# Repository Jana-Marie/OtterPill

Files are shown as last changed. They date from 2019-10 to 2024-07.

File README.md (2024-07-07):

# OtterPill

OtterPill is a 3$ STM32F072 devboard featuring USB 2.0 full-speed, a DFU Bootloader, a USB-PD Phy and Arduino nano alike pinout and size.

Changelog V1.2: BOM cost reduction by ~40%, PCB can be fully populated by JLCSMT, more efficient buck converter (PCB gets less warm at 20V), GND-hook for probing, Reset-Pin exposed as pad, power pads for 20V/5A

**How do I get an OtterPill?**

Via [tindie](https://www.tindie.com/products/jan_henrik/otterpill/) (if sold out DM via Twitter, I might have a few left ;))

## Building, Flashing and Frameworks

### Via Makefile and DFU (C, C++)

Or you can generate a basic firmware, with HAL init and Makefile, with CubeMX. The binary can then be build with make and flashed with dfu-utils. To enter DFU mode, press and hold the Button while plugging in power.

    $ make
    $ dfu-util -a 0 -s 0x08000000:leave -D build/firmware.bin

### Via Arduino

[You can build and flash the firmware via Arduino as described here.](https://github.com/stm32duino/Arduino_Core_STM32)

### Via PlatformIO

[https://gist.github.com/ansemjo/ab1c12f7c78abb140f7272501aff2a55](https://gist.github.com/ansemjo/ab1c12f7c78abb140f7272501aff2a55) Thank you [ansemjo](https://github.com/ansemjo) :3

### Via Nodate (野点) (C++, Ada)

[https://github.com/MayaPosch/Nodate](https://github.com/MayaPosch/Nodate)

### Rust

Thank you [@jamesmunns](https://github.com/jamesmunns)! :3

[https://github.com/jamesmunns/OtterPill-rs](https://github.com/jamesmunns/OtterPill-rs)

## Schematic

[HW v1.2/OtterPill.pdf](HW%20v1.2/OtterPill.pdf)

## Pinout

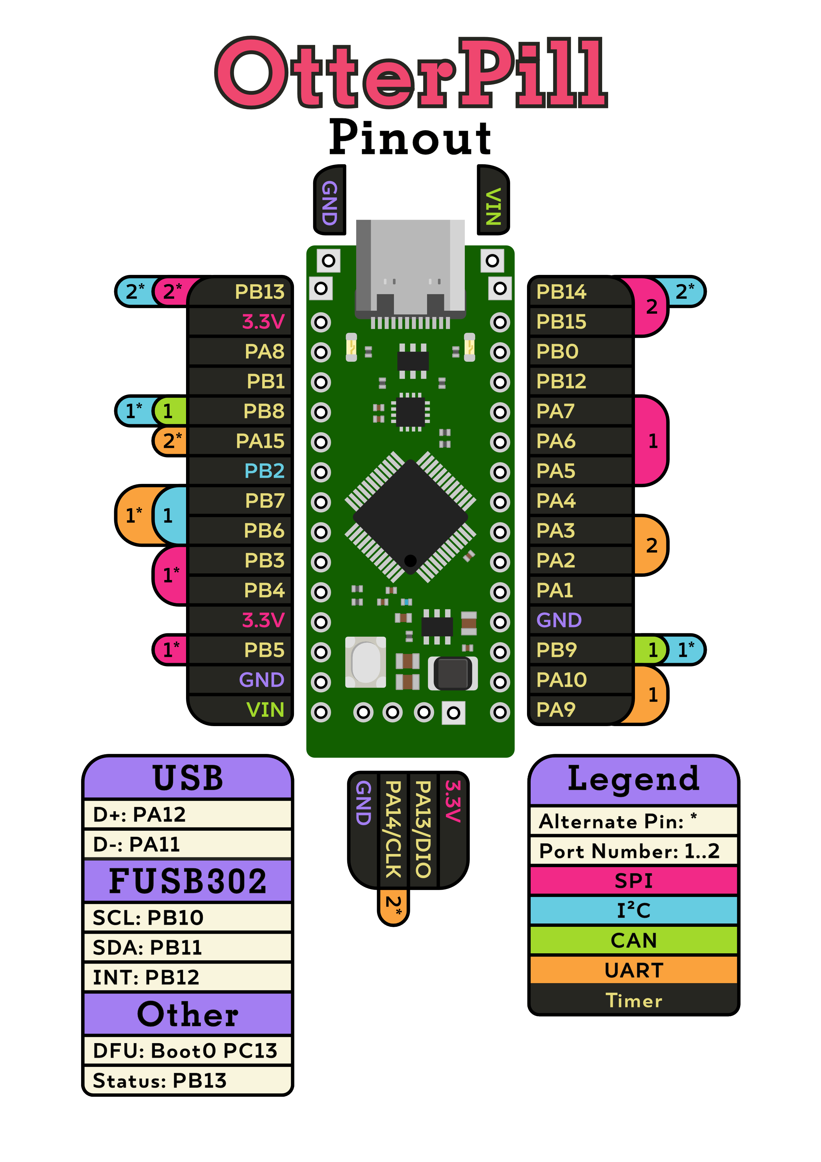
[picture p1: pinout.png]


Pinout by [SarahhhhFoster](https://github.com/SarahhhhFoster) :)

## Examples and projects

### Blink example firmware

[Blink/](Blink/)

### STM workshop based on OtterPill

[https://github.com/Jana-Marie/hackerhotel-stm-workshop](https://github.com/Jana-Marie/hackerhotel-stm-workshop)



### USB-PD example firmware

This is a working USB-PD example using ChibiOS, a new voltage can be requested by pressing the Button.

[https://github.com/Jana-Marie/USB-PD-Firmware](https://github.com/Jana-Marie/USB-PD-Firmware)

### IBM dials retrofit

[https://github.com/Jana-Marie/IBM-dials-retrofit](https://github.com/Jana-Marie/IBM-dials-retrofit)



## Shields and addons

Most Arduino shields should be compatible.

#### [USB-to-CAN-adapter](https://github.com/Jana-Marie/OtterPill-CAN-Adapter)

## Todo for HW v1.3

 - [x] Replace U1 with ESDU5V0H4
 - [x] ~~Add a TVS Diode to VBUS (e.g. SJD12A22L01)~~ -> Added series resistor to reduce ringing
 - [ ] Remove R8, R9
 - [x] ~~Redraw the FUSB302B Symbol~~ -> forgot why, works great
 - [x] ~~Consider switching to STUSB4500 (Easier PD requesting, same price)~~ -> FUSB works great, no need to change
 - [x] Add VBUS ADC

## Special thanks

[@jamesmunns](https://github.com/jamesmunns) for creating the Rust examples.

[@MayaPosch](https://github.com/MayaPosch) for creating the Nodate framework and adding the OtterPill.

[@ansemjo](https://github.com/ansemjo) for creating a PlatformIO configuration.

[@SarahhhhFoster](https://github.com/SarahhhhFoster) for creating the awesome pinout diagram.

## Images

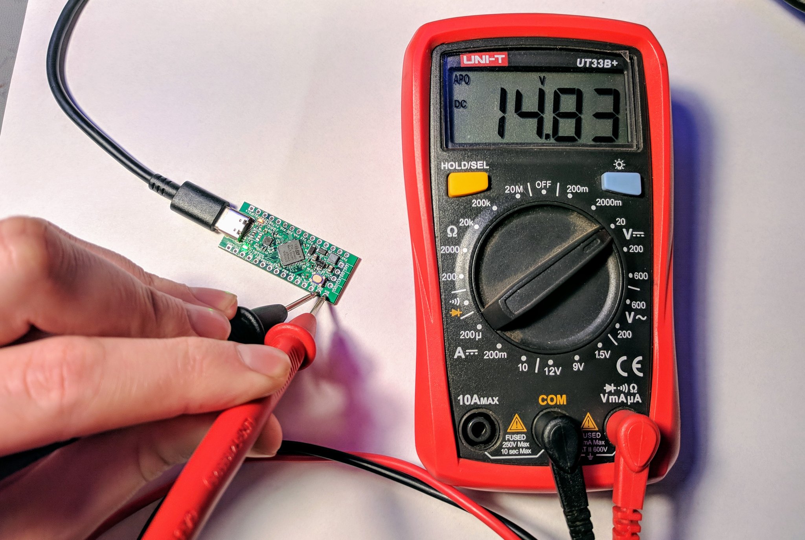
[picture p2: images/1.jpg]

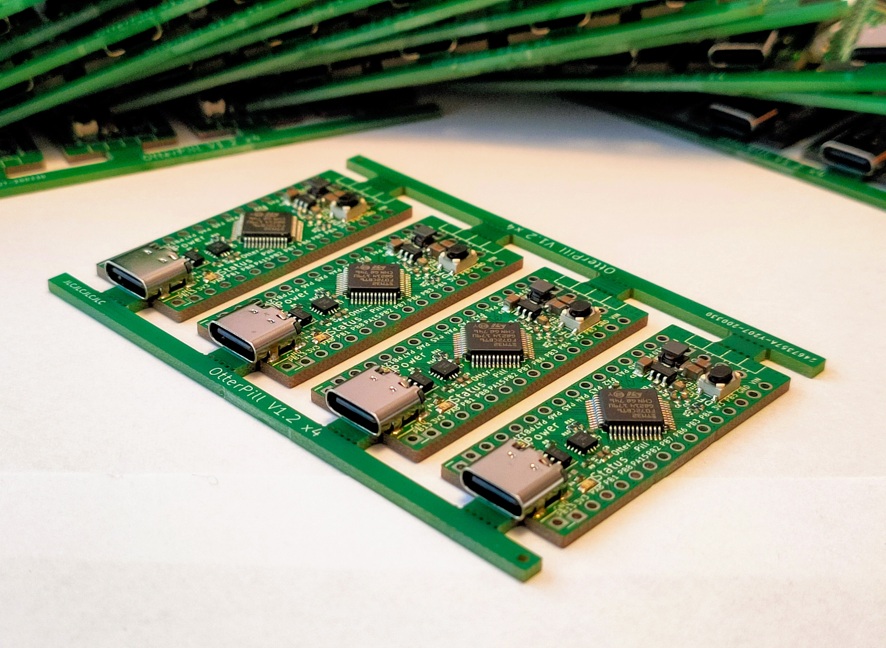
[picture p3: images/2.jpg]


### Rev 1.2

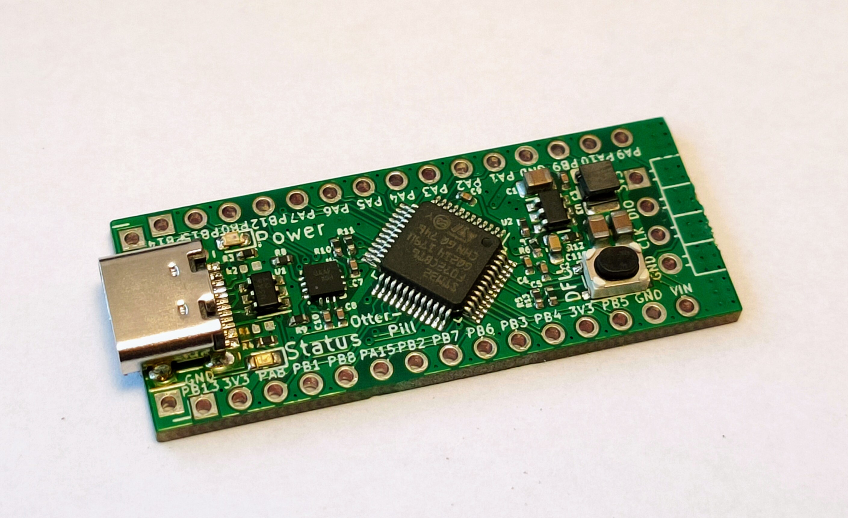
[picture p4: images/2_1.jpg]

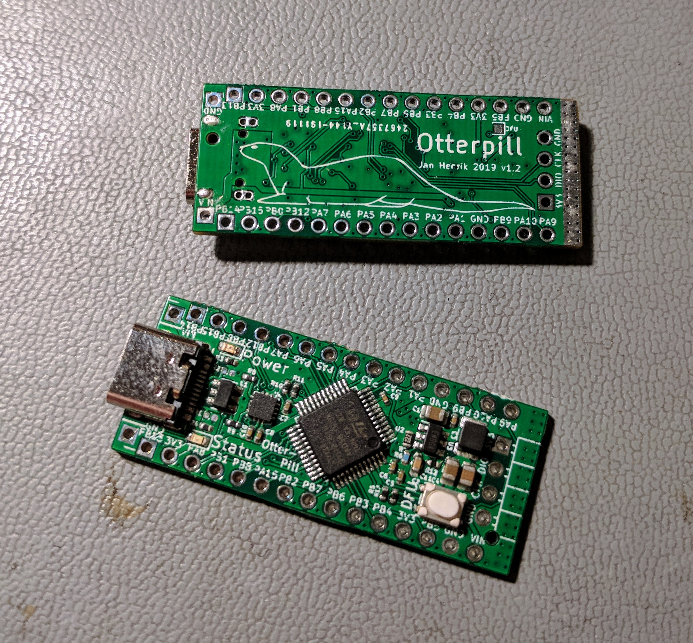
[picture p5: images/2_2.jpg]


### License

Copyright Jana Marie Hemsing 2027.

This source describes Open Hardware and is licensed under the CERN-OHL-S v2.

You may redistribute and modify this source and make products using it under
the terms of the CERN-OHL-S v2 (https://ohwr.org/cern_ohl_s_v2.txt).

This source is distributed WITHOUT ANY EXPRESS OR IMPLIED WARRANTY,
INCLUDING OF MERCHANTABILITY, SATISFACTORY QUALITY AND FITNESS FOR A
PARTICULAR PURPOSE. Please see the CERN-OHL-S v2 for applicable conditions.

Source location: https://github.com/Jana-Marie/OtterPill

As per CERN-OHL-S v2 section 4, should You produce hardware based on this
source, You must where practicable maintain the Source Location visible
on the external case of the Gizmo or other products you make using this
source.

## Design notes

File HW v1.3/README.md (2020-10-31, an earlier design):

# OtterPill

Hardware rev 1.3 not tested, gerber are broken.

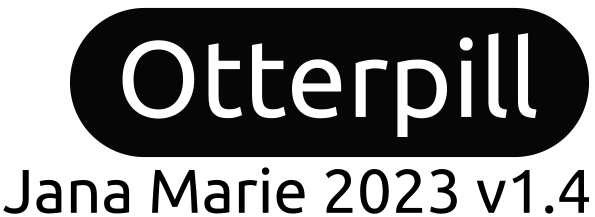
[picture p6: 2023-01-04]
HW v1.4/otterpill_1200.png

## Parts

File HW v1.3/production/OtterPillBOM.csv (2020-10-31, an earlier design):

Comment | Designator | Footprint | LCSC
10u 25V | C1,C4,C11 | Capacitor_SMD:C_0805_2012Metric | C15850
100n 50V | C2 | Capacitor_SMD:C_0603_1608Metric | C14663
100n 50V | C3,C5,C6,C7,C8,C9,C10,C12 | Capacitor_SMD:C_0402_1005Metric | C1525
LED RED | D1 | LED_SMD:LED_0603_1608Metric | C2286
LED GREEN | D2 | LED_SMD:LED_0603_1608Metric | C72043
USB-c | J1 | otter:USB-C 16Pin
4u7 | L1 | Inductor_SMD:L_1210_3225Metric | C86070
DNP | R1,R2 | Resistor_SMD:R_0402_1005Metric | dnp
100 | R13 | Resistor_SMD:R_0402_1005Metric | C25076
1 | R16 | Resistor_SMD:R_0603_1608Metric | C22936
3k3 | R5,R3,R4,R10,R11 | Resistor_SMD:R_0402_1005Metric | C25890
100k | R6,R12,R14 | Resistor_SMD:R_0402_1005Metric | C25741
22k | R7,R15 | Resistor_SMD:R_0402_1005Metric | C25768
0 | R8,R9 | Resistor_SMD:R_0402_1005Metric | C17168
DFU | SW1 | Button_Switch_SMD:SW_SPST_PTS810
USBLC6-4 | U1 | Package_TO_SOT_SMD:SOT-23-6 | C111212
STM32F072C8Tx | U2 | Package_QFP:LQFP-48_7x7mm_P0.5mm | C80488
SY8201 | U3 | Package_TO_SOT_SMD:SOT-23-6 | C108052
FUSB302BMPX | U4 | Package_DFN_QFN:WQFN-14-1EP_2.5x2.5mm_P0.5mm_EP1.45x1.45mm | C132291

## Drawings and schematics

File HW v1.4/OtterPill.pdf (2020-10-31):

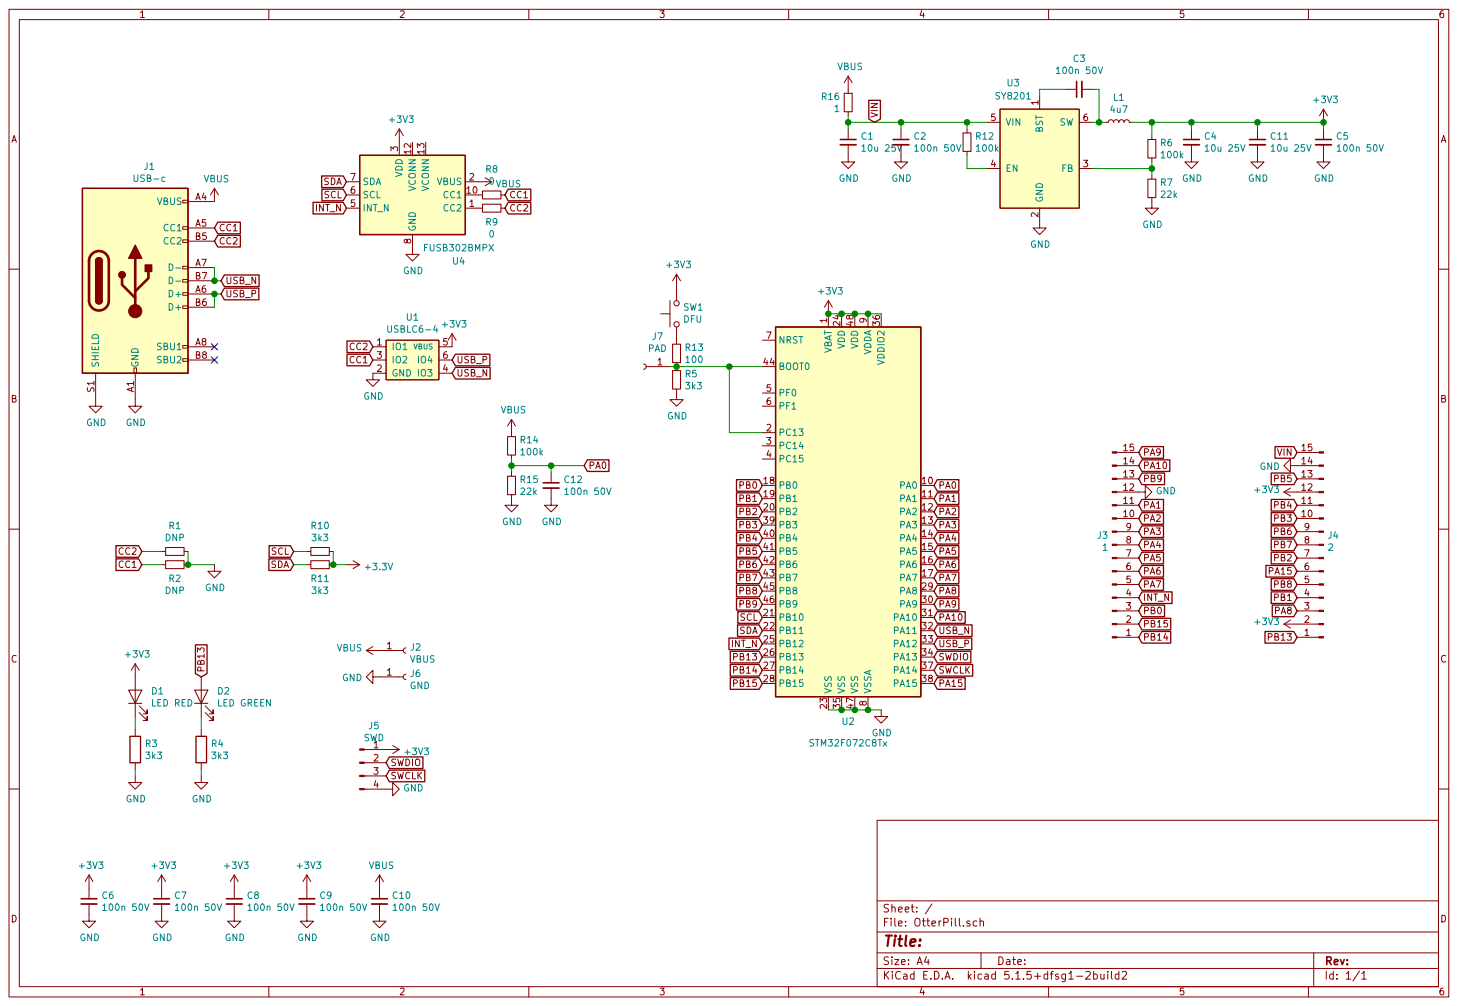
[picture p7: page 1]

2 FB 3 EN 4 VIN 5 SW 6 U3 SY8201 VBUS

1 PA0 10 PA1 11 PA2 12 PA3 13 PA4 14 PA5 15 PA6 16 PA7 17 PB0 18 PB1 19 PC13 2 PB2 20 PB10 21 PB11 22 VSS 23 VDD 24 PB12 25 PB13 26 PB14 27 PB15 28 PA8 29 PC14 3 PA9 30 PA10 31 PA11 32 PA12 33 PA13 34 VSS 35 VDDIO2 36 PA14 37 PA15 38 PB3 39 PC15 4 PB4 40 PB5 41 PB6 42 PB7 43 BOOT0 44 PB8 45 PB9 46 VSS 47 VDD 48 PF0 5 PF1 6 NRST 7 VSSA

Id: 1/1 Title: File: OtterPill.sch Sheet: / C12

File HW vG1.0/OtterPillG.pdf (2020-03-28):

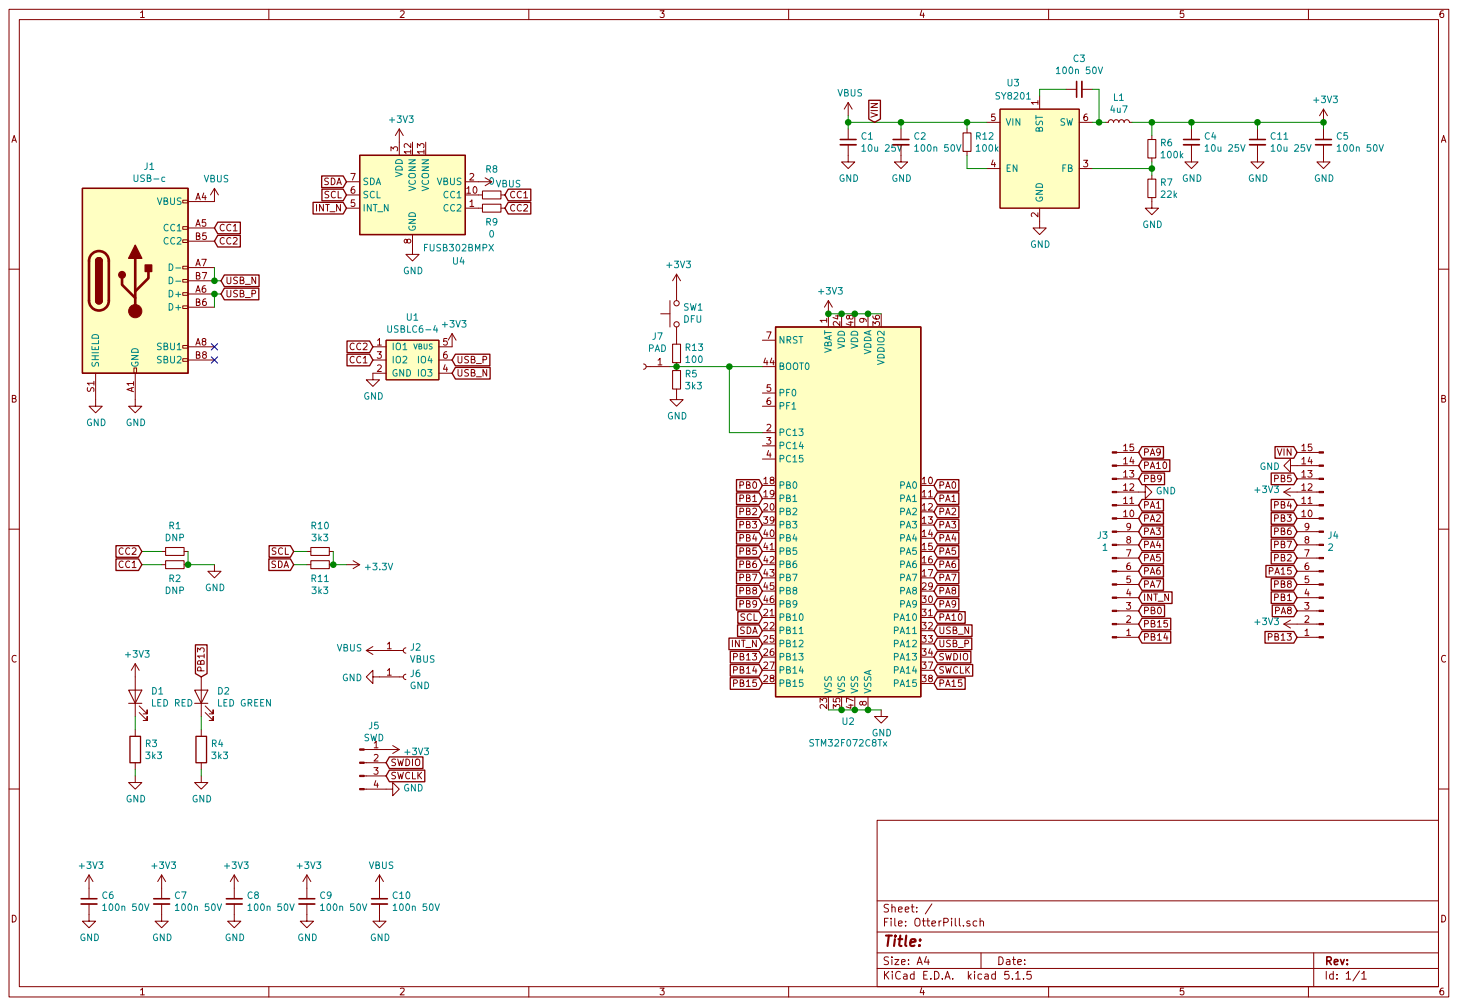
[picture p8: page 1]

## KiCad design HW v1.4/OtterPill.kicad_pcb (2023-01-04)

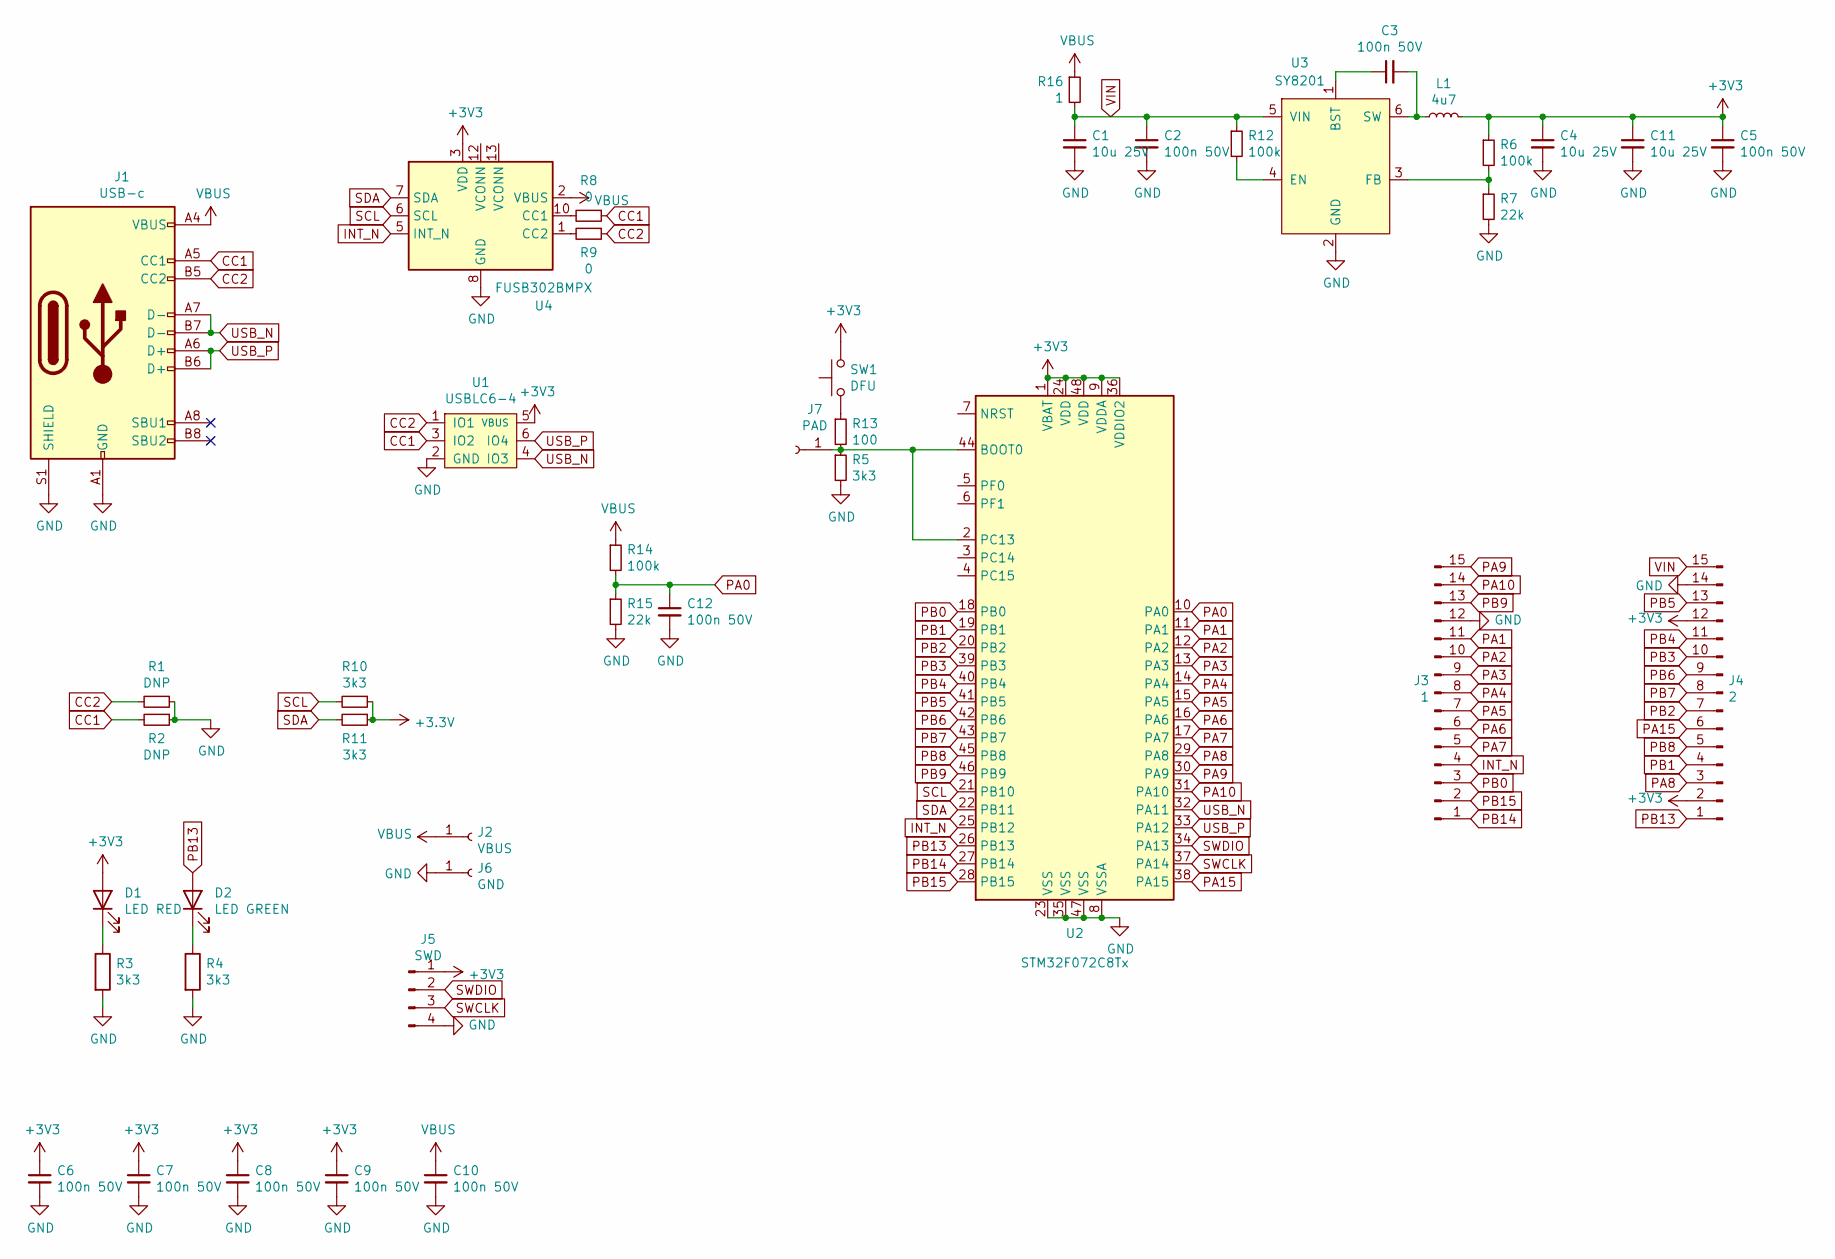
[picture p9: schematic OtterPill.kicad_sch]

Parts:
C1, C4, C11: 10u 25V; C_0805_2012Metric; LCSC C15850
C2: 100n 50V; C_0603_1608Metric
C3, C5, C6, C7, C8, C9, C10, C12: 100n 50V; C_0402_1005Metric
D1: LED RED; LED_0603_1608Metric
D2: LED GREEN; LED_0603_1608Metric
J1: USB-c; USB-C 16Pin
J2: VBUS; PinHeader_1x01_P2.54mm_Vertical
J3: 1; PinHeader_1x15_P2.54mm_Vertical
J4: 2; PinHeader_1x15_P2.54mm_Vertical
J5: SWD; PinHeader_1x04_P2.54mm_Horizontal
J6: GND; PinHeader_1x01_P2.54mm_Vertical
J7: PAD; TestPoint_Pad_1.0x1.0mm
L1: 4u7; L_1210_3225Metric; LCSC C86070
R1, R2: DNP; R_0402_1005Metric
R3, R4, R5, R10, R11: 3k3; R_0402_1005Metric
R6, R12, R14: 100k; R_0402_1005Metric
R7, R15: 22k; R_0402_1005Metric
R8, R9: 0; R_0402_1005Metric
R13: 100; R_0402_1005Metric
R16: 1; R_0603_1608Metric
SW1: DFU; SW_SPST_PTS810
U1: USBLC6-4; SOT-23-6
U2: STM32F072C8Tx; LQFP-48_7x7mm_P0.5mm
U3: SY8201; SOT-23-6
U4: FUSB302BMPX; WQFN-14-1EP_2.5x2.5mm_P0.5mm_EP1.45x1.45mm

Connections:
CC1: J1.A5 (CC1), R2.2, R8.1, U1.3 (IO2)
CC2: J1.B5 (CC2), R1.2, R9.1, U1.1 (IO1)
GND: C1.2, C2.2, C4.2, C5.2, C6.2, C7.2, C8.2, C9.2, C10.2, C11.2, C12.2, J1.A1 (GND), J1.A12 (GND), J1.B1 (GND), J1.B12 (GND), J1.S1 (SHIELD), J3.12, J4.14, J5.4, J6.1, R1.1, R2.1, R3.2, R4.2, R5.2, R7.2, R15.2, U1.2 (GND), U2.8 (VSSA), U2.23 (VSS), U2.35 (VSS), U2.47 (VSS), U3.2 (GND), U4.8 (GND), U4.9 (GND), U4.15 (GND)
INT_N: J3.4, U2.25 (PB12), U4.5 (INT_N)
unnamed: C3.1, U3.1 (BST)
unnamed: C3.2, L1.1, U3.6 (SW)
unnamed: D1.1 (K), R3.1
unnamed: D2.1 (K), R4.1
unnamed: J7.1, R5.1, R13.2, U2.2 (PC13), U2.44 (BOOT0)
unnamed: R6.2, R7.1, U3.3 (FB)
unnamed: R8.2, U4.10 (CC1), U4.11 (CC1)
unnamed: R9.2, U4.1 (CC2), U4.14 (CC2)
unnamed: R12.2, U3.4 (EN)
unnamed: R13.1, SW1.1
PA0: C12.1, R14.2, R15.1, U2.10 (PA0)
PA1: J3.11, U2.11 (PA1)
PA2: J3.10, U2.12 (PA2)
PA3: J3.9, U2.13 (PA3)
PA4: J3.8, U2.14 (PA4)
PA5: J3.7, U2.15 (PA5)
PA6: J3.6, U2.16 (PA6)
PA7: J3.5, U2.17 (PA7)
PA8: J4.3, U2.29 (PA8)
PA9: J3.15, U2.30 (PA9)
PA10: J3.14, U2.31 (PA10)
PA15: J4.6, U2.38 (PA15)
PB0: J3.3, U2.18 (PB0)
PB1: J4.4, U2.19 (PB1)
PB2: J4.7, U2.20 (PB2)
PB3: J4.10, U2.39 (PB3)
PB4: J4.11, U2.40 (PB4)
PB5: J4.13, U2.41 (PB5)
PB6: J4.9, U2.42 (PB6)
PB7: J4.8, U2.43 (PB7)
PB8: J4.5, U2.45 (PB8)
PB9: J3.13, U2.46 (PB9)
PB13: D2.2 (A), J4.1, U2.26 (PB13)
PB14: J3.1, U2.27 (PB14)
PB15: J3.2, U2.28 (PB15)
SCL: R10.2, U2.21 (PB10), U4.6 (SCL)
SDA: R11.2, U2.22 (PB11), U4.7 (SDA)
SWCLK: J5.3, U2.37 (PA14)
SWDIO: J5.2, U2.34 (PA13)
USB_N: J1.A7 (D-), J1.B7 (D-), U1.4 (IO3), U2.32 (PA11)
USB_P: J1.A6 (D+), J1.B6 (D+), U1.6 (IO4), U2.33 (PA12)
VBUS: C10.1, J1.A4 (VBUS), J1.A9 (VBUS), J1.B4 (VBUS), J1.B9 (VBUS), J2.1, R14.1, R16.1, U4.2 (VBUS)
VIN: C1.1, C2.1, J4.15, R12.1, R16.2, U3.5 (VIN)

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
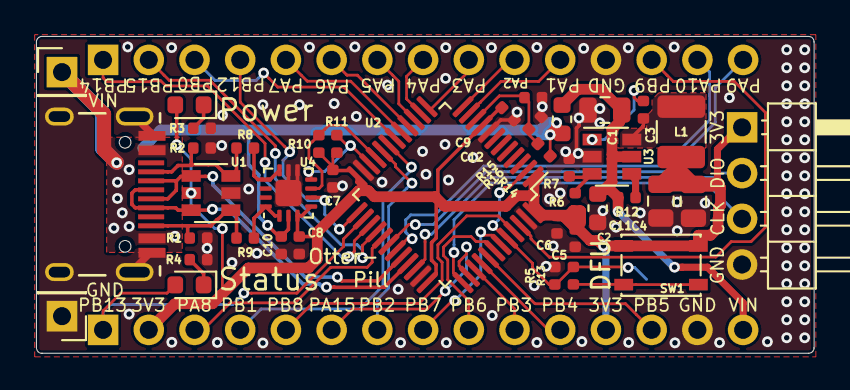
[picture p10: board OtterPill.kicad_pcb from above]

Board: 2 copper layers, 43.2 x 17.6 mm, 43 parts (1 on the bottom side), 48 nets.

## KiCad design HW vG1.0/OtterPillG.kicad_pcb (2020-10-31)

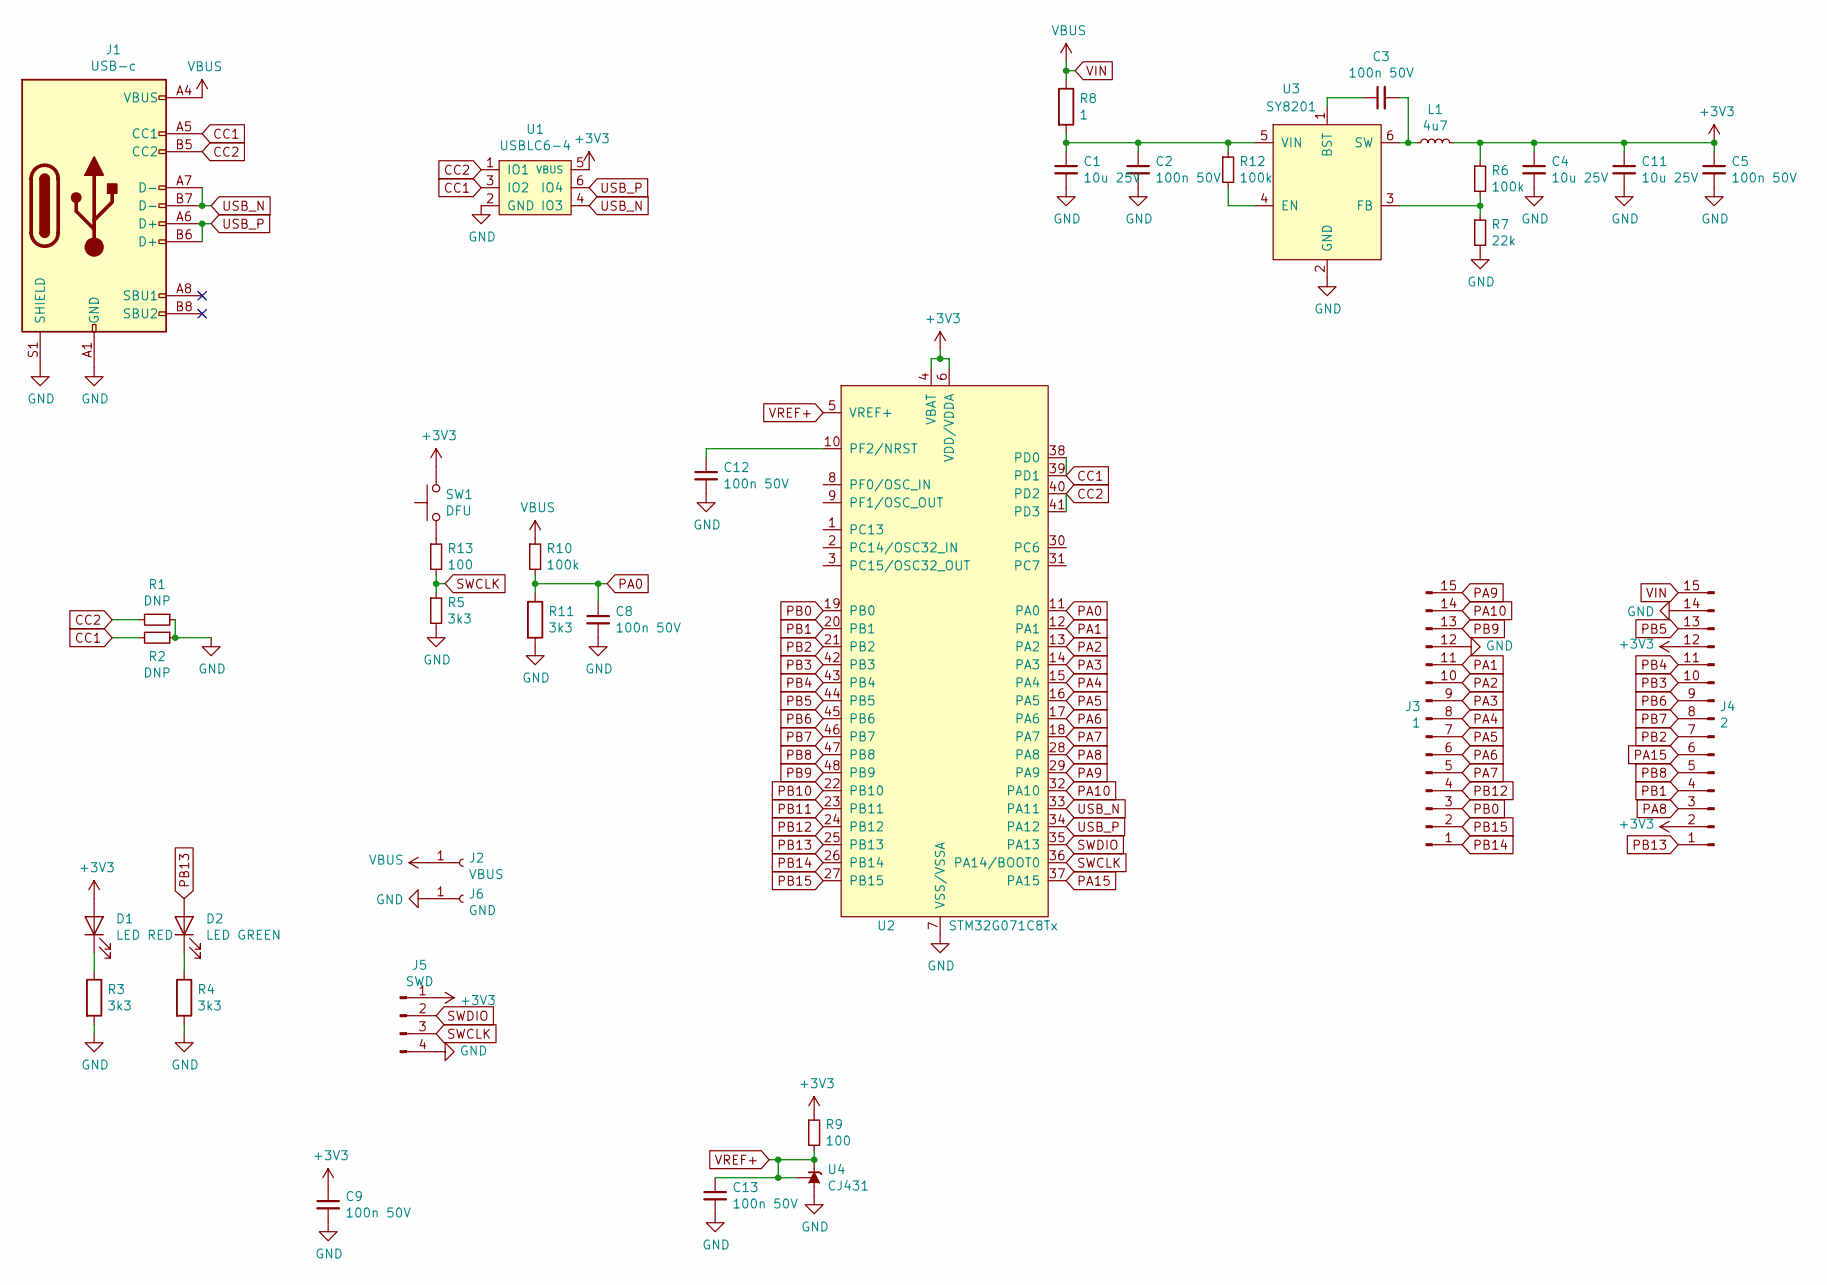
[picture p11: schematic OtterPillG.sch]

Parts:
C1, C4, C11: 10u 25V; C_0805; LCSC C15850
C2: 100n 50V; C_0603
C3, C5, C8, C9, C12, C13: 100n 50V; C_0402
D1: LED RED; LED_0603_1608Metric
D2: LED GREEN; LED_0603_1608Metric
J1: USB-c; USB-C 16Pin
J2: VBUS; PinHeader_1x01_P2.54mm_Vertical
J3: 1; PinHeader_1x15_P2.54mm_Vertical
J4: 2; PinHeader_1x15_P2.54mm_Vertical
J5: SWD; PinHeader_1x04_P2.54mm_Horizontal
J6: GND; PinHeader_1x01_P2.54mm_Vertical
L1: 4u7; L_1210_3225Metric; LCSC C86070
R1, R2: DNP; R_0402
R3, R4, R5, R11: 3k3; R_0402
R6, R10, R12: 100k; R_0402
R7: 22k; R_0402
R8: 1; R_0805
R9, R13: 100; R_0402
SW1: DFU; SW_SPST_PTS810
U1: USBLC6-4; SOT-23-6
U2: STM32G071C8Tx; TQFP-48_7x7mm_P0.5mm
U3: SY8201; SOT-23-6
U4: CJ431; SOT-23

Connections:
+3V3: C4.1, C5.1, C9.1, C11.1, D1.2 (A), J4.2, J4.12, J5.1, L1.2, R6.1, R9.1, SW1.2, U1.5 (VBUS), U2.4 (VBAT), U2.6 (VDD/VDDA)
CC1: J1.A5 (CC1), R2.2, U1.3 (IO2), U2.38 (PD0), U2.39 (PD1)
CC2: J1.B5 (CC2), R1.2, U1.1 (IO1), U2.40 (PD2), U2.41 (PD3)
GND: C1.2, C2.2, C4.2, C5.2, C8.2, C9.2, C11.2, C12.2, C13.2, J1.A1 (GND), J1.A12 (GND), J1.B1 (GND), J1.B12 (GND), J1.S1 (SHIELD), J3.12, J4.14, J5.4, J6.1, R1.1, R2.1, R3.2, R4.2, R5.2, R7.2, R11.2, U1.2 (GND), U2.7 (VSS/VSSA), U3.2 (GND), U4.3 (A)
unnamed: C1.1, C2.1, R8.2, R12.1, U3.5 (VIN)
unnamed: C3.1, U3.1 (BST)
unnamed: C3.2, L1.1, U3.6 (SW)
unnamed: C12.1, U2.10 (PF2/NRST)
unnamed: D1.1 (K), R3.1
unnamed: D2.1 (K), R4.1
unnamed: R6.2, R7.1, U3.3 (FB)
unnamed: R12.2, U3.4 (EN)
unnamed: R13.1, SW1.1
PA0: C8.1, R10.2, R11.1, U2.11 (PA0)
PA1: J3.11, U2.12 (PA1)
PA2: J3.10, U2.13 (PA2)
PA3: J3.9, U2.14 (PA3)
PA4: J3.8, U2.15 (PA4)
PA5: J3.7, U2.16 (PA5)
PA6: J3.6, U2.17 (PA6)
PA7: J3.5, U2.18 (PA7)
PA8: J4.3, U2.28 (PA8)
PA9: J3.15, U2.29 (PA9)
PA10: J3.14, U2.32 (PA10)
PA15: J4.6, U2.37 (PA15)
PB0: J3.3, U2.19 (PB0)
PB1: J4.4, U2.20 (PB1)
PB2: J4.7, U2.21 (PB2)
PB3: J4.10, U2.42 (PB3)
PB4: J4.11, U2.43 (PB4)
PB5: J4.13, U2.44 (PB5)
PB6: J4.9, U2.45 (PB6)
PB7: J4.8, U2.46 (PB7)
PB8: J4.5, U2.47 (PB8)
PB9: J3.13, U2.48 (PB9)
PB10: U2.22 (PB10)
PB11: U2.23 (PB11)
PB12: J3.4, U2.24 (PB12)
PB13: D2.2 (A), J4.1, U2.25 (PB13)
PB14: J3.1, U2.26 (PB14)
PB15: J3.2, U2.27 (PB15)
SWCLK: J5.3, R5.1, R13.2, U2.36 (PA14/BOOT0)
SWDIO: J5.2, U2.35 (PA13)
USB_N: J1.A7 (D-), J1.B7 (D-), U1.4 (IO3), U2.33 (PA11)
USB_P: J1.A6 (D+), J1.B6 (D+), U1.6 (IO4), U2.34 (PA12)
VIN: J1.A4 (VBUS), J1.A9 (VBUS), J1.B4 (VBUS), J1.B9 (VBUS), J2.1, J4.15, R8.1, R10.1
VREF+: C13.1, R9.2, U2.5 (VREF+), U4.1 (REF), U4.2 (K)

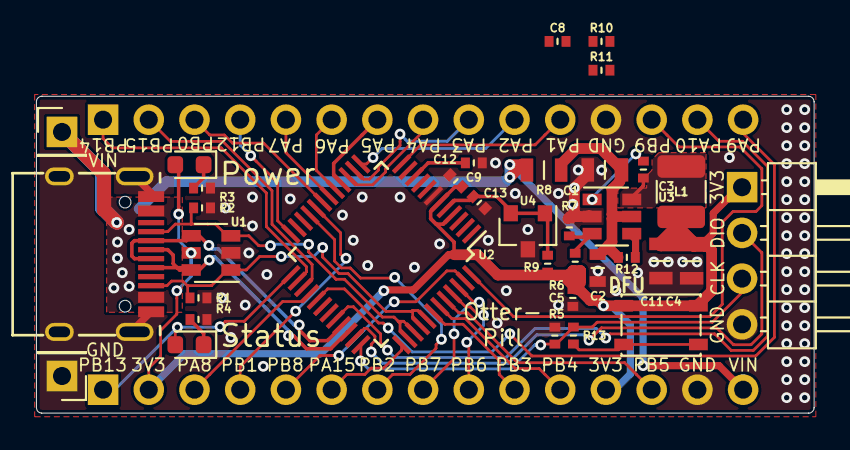
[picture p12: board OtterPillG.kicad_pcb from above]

Board: 2 copper layers, 43.2 x 17.6 mm, 37 parts (0 on the bottom side), 45 nets.

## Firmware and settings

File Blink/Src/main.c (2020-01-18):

#include "main.h"

void SystemClock_Config(void);
static void MX_GPIO_Init(void);

int main(void)
{
  HAL_Init();
  SystemClock_Config();

  MX_GPIO_Init();

  while (1)
  {
    HAL_GPIO_WritePin(GPIOB,GPIO_PIN_13,1);
    HAL_Delay(1000);
    HAL_GPIO_WritePin(GPIOB,GPIO_PIN_13,0);
    HAL_Delay(1000);
  }
}

void SystemClock_Config(void)
{
  RCC_OscInitTypeDef RCC_OscInitStruct = {0};
  RCC_ClkInitTypeDef RCC_ClkInitStruct = {0};

  RCC_OscInitStruct.OscillatorType = RCC_OSCILLATORTYPE_HSI;
  RCC_OscInitStruct.HSIState = RCC_HSI_ON;
  RCC_OscInitStruct.HSICalibrationValue = RCC_HSICALIBRATION_DEFAULT;
  RCC_OscInitStruct.PLL.PLLState = RCC_PLL_NONE;
  HAL_RCC_OscConfig(&RCC_OscInitStruct);

  RCC_ClkInitStruct.ClockType = RCC_CLOCKTYPE_HCLK|RCC_CLOCKTYPE_SYSCLK
                              |RCC_CLOCKTYPE_PCLK1;
  RCC_ClkInitStruct.SYSCLKSource = RCC_SYSCLKSOURCE_HSI;
  RCC_ClkInitStruct.AHBCLKDivider = RCC_SYSCLK_DIV1;
  RCC_ClkInitStruct.APB1CLKDivider = RCC_HCLK_DIV1;

  HAL_RCC_ClockConfig(&RCC_ClkInitStruct, FLASH_LATENCY_0);
}

static void MX_GPIO_Init(void)
{
  GPIO_InitTypeDef GPIO_InitStruct = {0};

  __HAL_RCC_GPIOB_CLK_ENABLE();
  __HAL_RCC_GPIOA_CLK_ENABLE();

  HAL_GPIO_WritePin(GPIOB, GPIO_PIN_13, GPIO_PIN_RESET);

  GPIO_InitStruct.Pin = GPIO_PIN_13;
  GPIO_InitStruct.Mode = GPIO_MODE_OUTPUT_PP;
  GPIO_InitStruct.Pull = GPIO_NOPULL;
  GPIO_InitStruct.Speed = GPIO_SPEED_FREQ_LOW;
  HAL_GPIO_Init(GPIOB, &GPIO_InitStruct);

}

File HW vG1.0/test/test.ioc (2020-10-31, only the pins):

Mcu.UserName=STM32G071C8Tx
PA1.Signal=ADC1_IN1
PA13.Signal=SYS_SWDIO
PA14-BOOT0.Signal=SYS_SWCLK
PA2.Signal=LPUART1_TX
PA3.Signal=LPUART1_RX
PB13.Signal=GPIO_Output
PD0.Signal=UCPD2_CC1
PD1.Signal=UCPD2_DBCC1
PD2.Signal=UCPD2_CC2
PD3.Signal=UCPD2_DBCC2

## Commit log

2019-05-05 initital commit
    [OtterPill.kicad_pcb, OtterPill.sch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]
2019-05-06 added gerber
    [OtterPill-B_Cu.gbl, OtterPill-B_Mask.gbs, OtterPill-B_Paste.gbp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]
2019-10-16 updated PCB and gerber
    [OtterPill-B.Cu.gbl, OtterPill-B.Mask.gbs, OtterPill-B.Paste.gbp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]
2019-10-16 updated gerber
    [OtterPill-B.Cu.gbl, OtterPill-B.Mask.gbs, OtterPill-B.Paste.gbp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]
2019-10-16 removed old gerber
    [OtterPill-B_Cu.gbl, OtterPill-B_Mask.gbs, OtterPill-B_Paste.gbp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]
2019-10-18 added BOM
    [OtterPill.csv]
2019-10-20 updated otterpill to V1.2
    [OtterPill.csv, OtterPill.kicad_pcb, OtterPill.sch]
2019-10-23 added HW 1.1 files
    [OtterPill-B.Cu.gbl, OtterPill-B.Mask.gbs, OtterPill-B.Paste.gbp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]
2019-10-23 moved HW 1.2 files
    [1-click-bom.tsv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]
2019-10-24 updated V1.2
    [OtterPill-B.Cu.gbl, OtterPill-B.Mask.gbs, OtterPill-B.Paste.gbp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]
2019-11-17 finalized V1.2
    [1-click-bom.tsv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]
2019-12-20 updated values
    [OtterPill.sch, OtterPillBOM.csv]
2019-12-21 schematic cleanup
    [OtterPill.kicad_pcb, OtterPill.sch]
2019-12-21 fixed bom
    [OtterPill.csv]
2020-01-25 Add OtterPill v1.2 Schematic PDF
2020-03-28 added x4 production files
    [OtterPill-top-pos.csv]
2020-03-28 added edgerails
    [edgerails-B_Cu.gbl, edgerails-B_Mask.gbs, edgerails-B_Paste.gbp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]
2020-03-28 updated bom
    [OtterPillBOM.csv]
2020-04-15 added boms
    [OtterPill-top-pos-x2.csv, OtterPill-top-pos-x4.csv]
2020-04-15 fixed 100k
    [OtterPillBOM.csv]
2020-04-22 added images
    [OtterPill.kicad_pcb]
2020-09-14 added G072 version
    [OtterPill-B_Cu.gbl, OtterPill-B_Mask.gbs, OtterPill-B_Paste.gbp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]
2020-09-14 removed old files
    [OtterPill-B_Cu.gbl, OtterPill-B_Mask.gbs, OtterPill-B_Paste.gbp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]
2020-10-31 updated v1.3
    [OtterPill-B_Cu.gbl, OtterPill-B_Mask.gbs, OtterPill-B_Paste.gbp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]
2020-10-31 updated vG1.0
    [OtterPillG-B_Cu.gbl, OtterPillG-B_Mask.gbs, OtterPillG-B_Paste.gbp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]
2020-10-31 added production files
    [OtterPillBOM.csv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]
2023-01-04 added kicad files
    [OtterPill.kicad_pcb, OtterPill.kicad_sch]
2023-01-04 added silkscreen art
2023-01-04 fixed schematic issue
    [OtterPill.kicad_sch]
